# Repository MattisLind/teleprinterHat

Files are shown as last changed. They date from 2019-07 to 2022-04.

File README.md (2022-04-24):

# teleprinterHat
A RaspberryPi HAT that interfaces a old school teleprinter

Finished board

Schematic

## History
Some time ago I started planning to get an old Lorenz Lo15 teleprinter working. Then arose the question about how to interface those old machines to the real world. While investigating this I gained quite some knowledge of teleprinter interfacing and Telex networks. For example the normal line voltage of a US teleprinter line is 120VDC and the current is 60 mA.

Preferbly the interfacing should be as simple and small as possible. Using some big expensive 50 Hz 120 VAC transformer, rectifier and 2kOhm 6W resistor was not on the table.

Preferbly the circuit should be able to run off a standard USB charger. I.e. 5V 500mA. Experimenting a bit with a stepup circuit gave that is perfectly possibly to step up 5V to 120V. SO one could ask how could a 5V 500 mA supply be able to supply the power for a 120V 60mA load. Of course it cannot, but the problem lies in the fact tat most of the power is absorbed in the current limiting 2kOhm resistor of the old school circuit. The actual teleprinter has an internal resistance of approximately 100 Ohm. So why 120V? The reason for 120V is to achieve a fast pull of the magnet inside the teleprinter. After the initial pull the steady state voltage drop is between 5 to 10 V at 60mA. 

When I started to work with this project I also made an announcment in the i-Telex forum and got a reply from Jochen that had done something similar and the same point in time. What a coincidence! [piTelex project](https://github.com/fablab-wue/piTelex)

Jochen have compiled a lot of interesting and useful information there but the project is based on a Raspberry Pi and cannt be used stand alone. One of my requirements are that it should be able to run completely stand alone. I don't want the bloat of a Linux kernel just to push a few bytes back and forth!

## Requirments

So I put together a list of requirments

1. Shall only need 5V supply. The generation of up 120V DC is built into the device. Using a step-up converter.
2. Low power consumption. No 6W 2kOhm resistor. Use PWM to control the current through the solenoid. 
3. Configurable for 60mA, 40mA and 20mA current loop.
4. ~~Automatically detect the line voltage to use based on line current and required rise time of current through coil. Measure what kinde of loop inductance there is and adapt to a possibly resistive remote.~~ Deemed not possible with current design.
5. Interface directly to RS-232-E levels on board. (option) using a MAX232 or equivalent and a couple of capacitors
6. Interface directly to USB using FTDI chip on board (option)
7. Do baudot to ASCII conversion locally.
8. Do baudrate adaption locally. Configurable teleprinter baudrate to support at least 45,5, 50, 56, 75, 100 and 110 bps.
9. Configurable uplink RS-232 interface 50, 75, 110, 150, 300 bps to adapt to all sorts of hosts.
10. Dimensions that fits the Rpi Zero preferbly but if it is getting to crammed a standar Rpi HAT is the choice.
11. The RPI should be able to control all settings of the device from GPIO ports. Possibly use SPI to make more advanced configuration possible.
13. LEDs connected to RPi GPIOs to indicate mode or state in RPi Software.
14. Jumpers connected to the RPI GPIOs to control the RPI software and selection om mode of operation.
15. The RPi shall automatically boot up and select operating mode depending on jumpers. For example i-Telex or news RSS, RasPi serial console. No interaction using screen or keyboard connected to the RPi shall be necessary.
16. Relay to support reversal of polarity of the line current (optional)
17. Be able to drive a SSR that can be used to enable power to the teleprinter
18. Diagnostic LED to indicate line malfunction. I.e. to detect an open loop 
19. Current loop interface to support old PDP-11 current loops using opto couplers.
20. Use two 2.5 mm mono plugs for interfacing the teleprinter.
21. Diagnostic LED to indicate what line voltage is selected. Maybe multicolor RGB LED?
22. RX and TX LEDs
23. Support for FSG device (optional)
24. A few test sequences are built in. Continous RY and "The quick brown fox jumps over the lazy dog"
25. Flow control using XON/XOFF, RTS/CTS or DSR/DTR. Selcteable using jumpers. Both via USB/FTDI or RS-232

## Stepup converter

The first thing to verify is that the idea of the step up converter was ok. I did a small circuit board to check the circuit and during this I found that the parameters of the coil si very importantant. It has to have a high enough Isat. Then the choice of MOSFET is important. The MOSFET has to full turn on at only 5V gate voltage which is what is available in this circuit. Thus Vgs(ON) is of high interest. Then to deliver as much of the 5V into the coil means that as little loss of energy in the MOSFET is important. The rDS(ON) is the parameter to look for. 

Step up hook up

It turned out that this circuit worked well and could easily deliver 120VDC.

## Using PWM to control the selector magnet.

The main idea with this circuit is to generate the required 60mA with as litle loss as possible. By measuring the current in the loop using a small resistance and then hysteresis regulate the current using a PNP transistor as switch. The current is feed through a small inductor which will not saturate. 

As the switch transistor is swithced on the current in the inductor will increase with time. When it reach the upper hysteresis limit the transistor will switch off. The current in the inductance will continue to flow through the diode and the resistor. As the current reaches the lower limit the transistor will switch on again. 

The receiver magnet inductance will only come into play when going from sending a space bit to a mark bit. Then the large total inductance will keep the regulator switched on for several milliseconds depending on the inductance in the magenet. As soon as the line current level is reached the magnetcoil is fully saturated and will act as a pure resistance. The implementation is based on a op-amp for measuring the differential volatage of the current measuring resistor. Then a fast comparator with a 5% hysterisis band generates a square wave from the incoming sawtooth signal. This squarewave then drives the switch transistors. 

The transistor switch is composed of a PNP transistor as the main switch transistor and a NPN level cvonversion transistor driving the PNP transistor through a resistance.

The reference voltage to the hysteresis comparator is supplied from a PWM signal output of the mikroprocessor. Thereby making it possible to control the current level through software. The PWM signal is low pass filtered in a simple RC network and then buffered through a buffering op-amp.

I did a quick mockup with components at hand but it turned out that the comparator needed to be pretty fast and the transistor switch as well. It simply didn't work very well. I decided to try to do simulations in LTspice before doing further breadboarding. 

Searches on internet gave a decent circuit for a P-MOS FET based switch. Simulations in LTspice gave proper values for resistors and capacitors and it was time to make a peroper board.

Current source prototype

Schematic.

Current source prototype schematic

The design also included an PNP and NPN transistor to handle keying of the sening signal.

A simple NPN transistor is used to key the current in the loop ON/OFF. This has to be done without any free-wheeling diode since otherwise the release of the magnet when swithcing of the current will be very much delayed and might not even happen at all. 

Initial tests showed good performance. It could regulate the desired current at varying line voltages without any problem.

Current source regulating

This picture show the voltage over the measurement resistor. The scale is 100mV per division and the resistor is 51 ohm so the interval it is regulating over is +/- 2mA as designed.

Running the circuit with the actual Lorenz Lo15 teleprinter also yielded good results.

Current source regulating

Keying the signal, 90V line voltage, 40 mA line current. The large spikes are created by the selector magnet as the switch cuts off. Had initial problems that the choosen PNP transistor was unable to cope with these. Intalled a 300 V PNP transistor and a MOV to handle the spikes. Worked well. But I am considering using a TVS instead.

Current source regulating

This picture shows when regulating the 40mA output to the selector magnet when the line is in marking state.

## Prototyping the Step up converter and current source 

I already did a prototype of the step-up converter. But the MOSFET used was quite big and overdimensioned. I also wanted to use a proper gate driver as well as off load the micro controller doing the chore of keeping the PWM rate continuosly measuring the output voltage. A separate, very small, switch control IC, cheap as well, was a better choice. So I designed another prototype board to test out these concept as well as testing the current loop circuit.

Current source regulating

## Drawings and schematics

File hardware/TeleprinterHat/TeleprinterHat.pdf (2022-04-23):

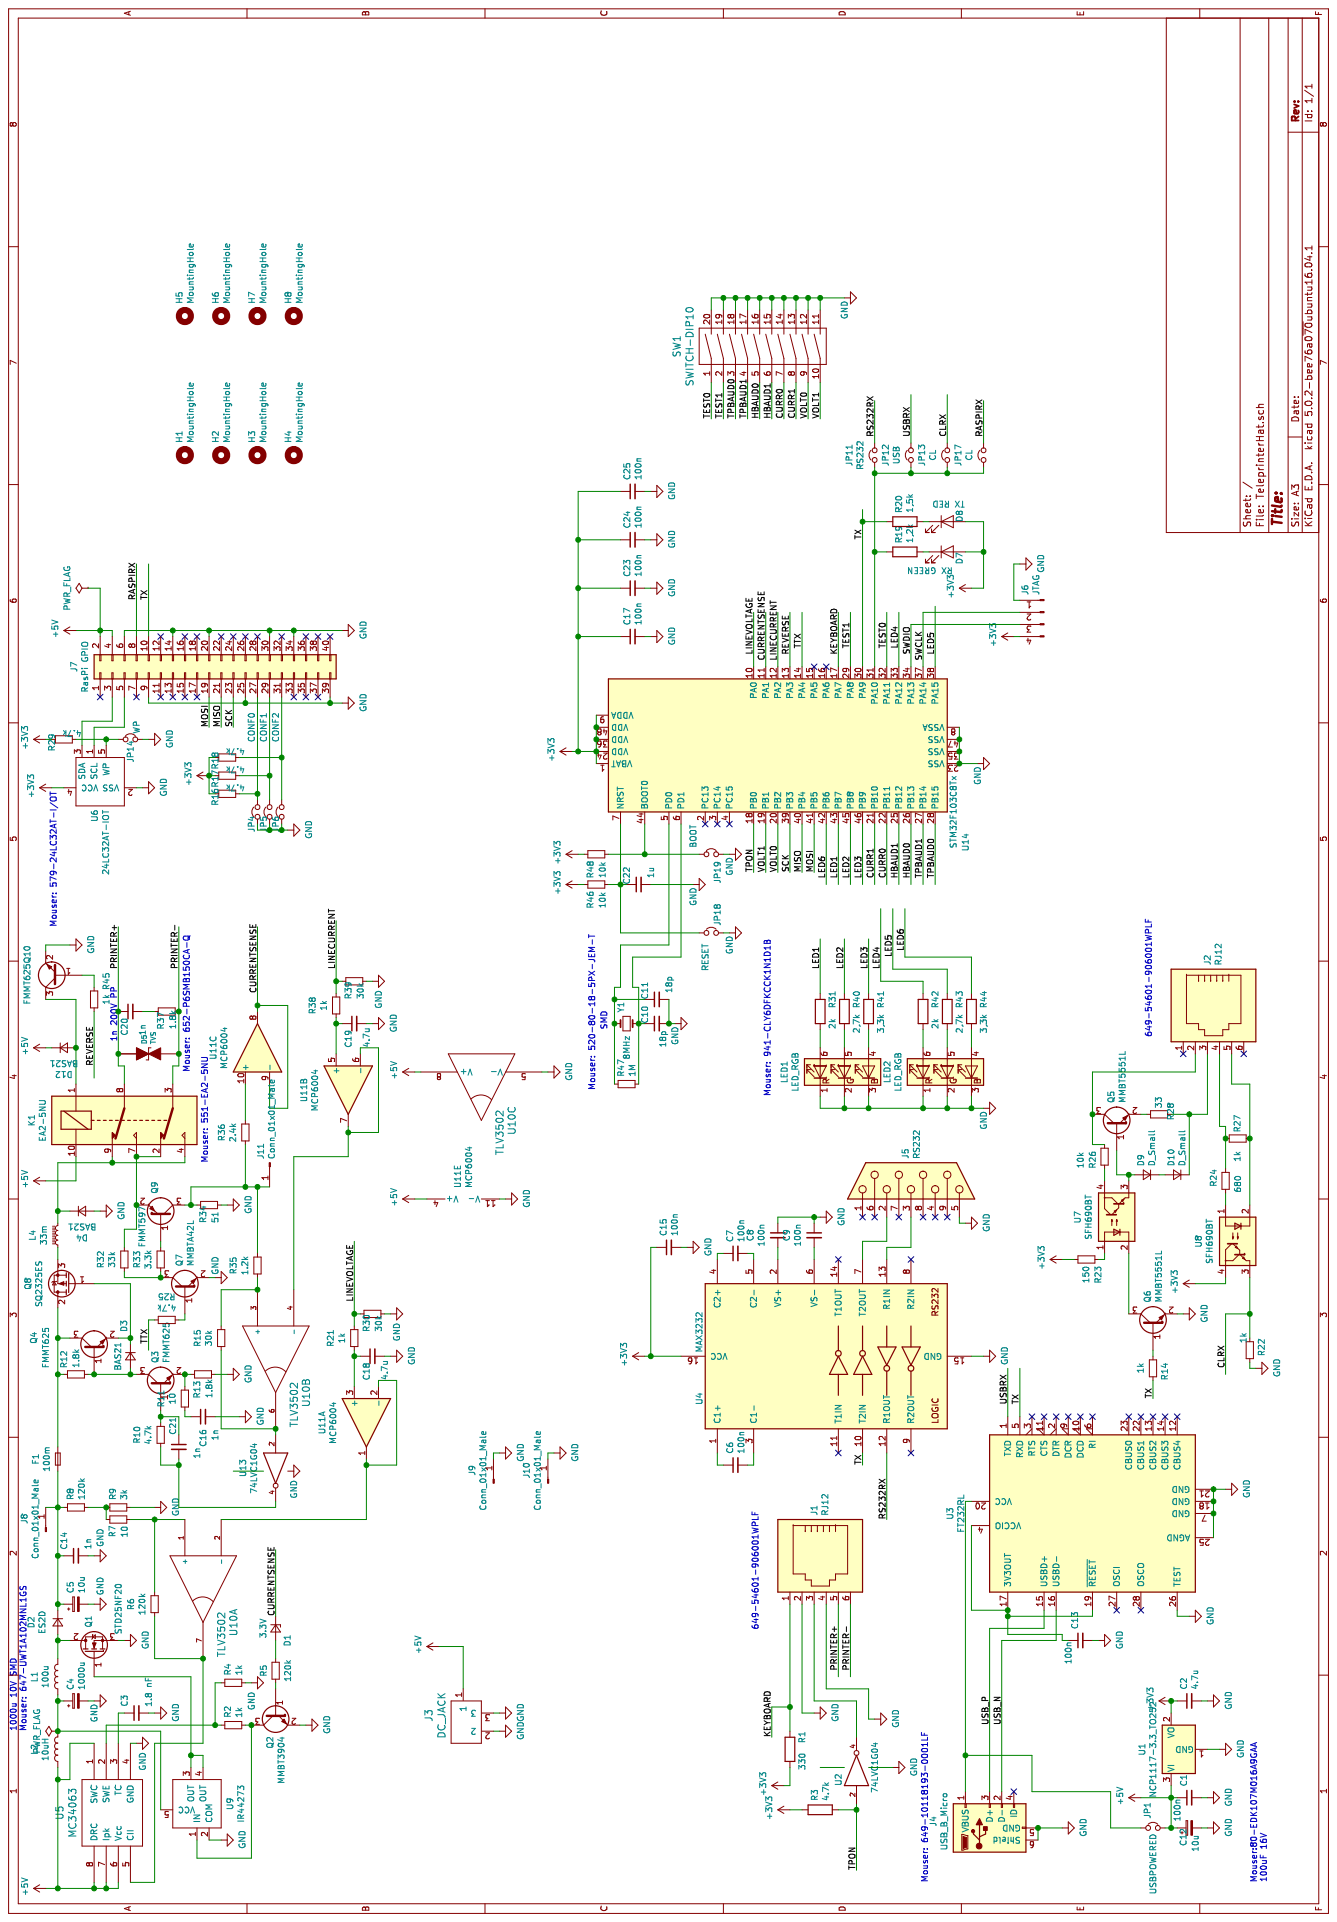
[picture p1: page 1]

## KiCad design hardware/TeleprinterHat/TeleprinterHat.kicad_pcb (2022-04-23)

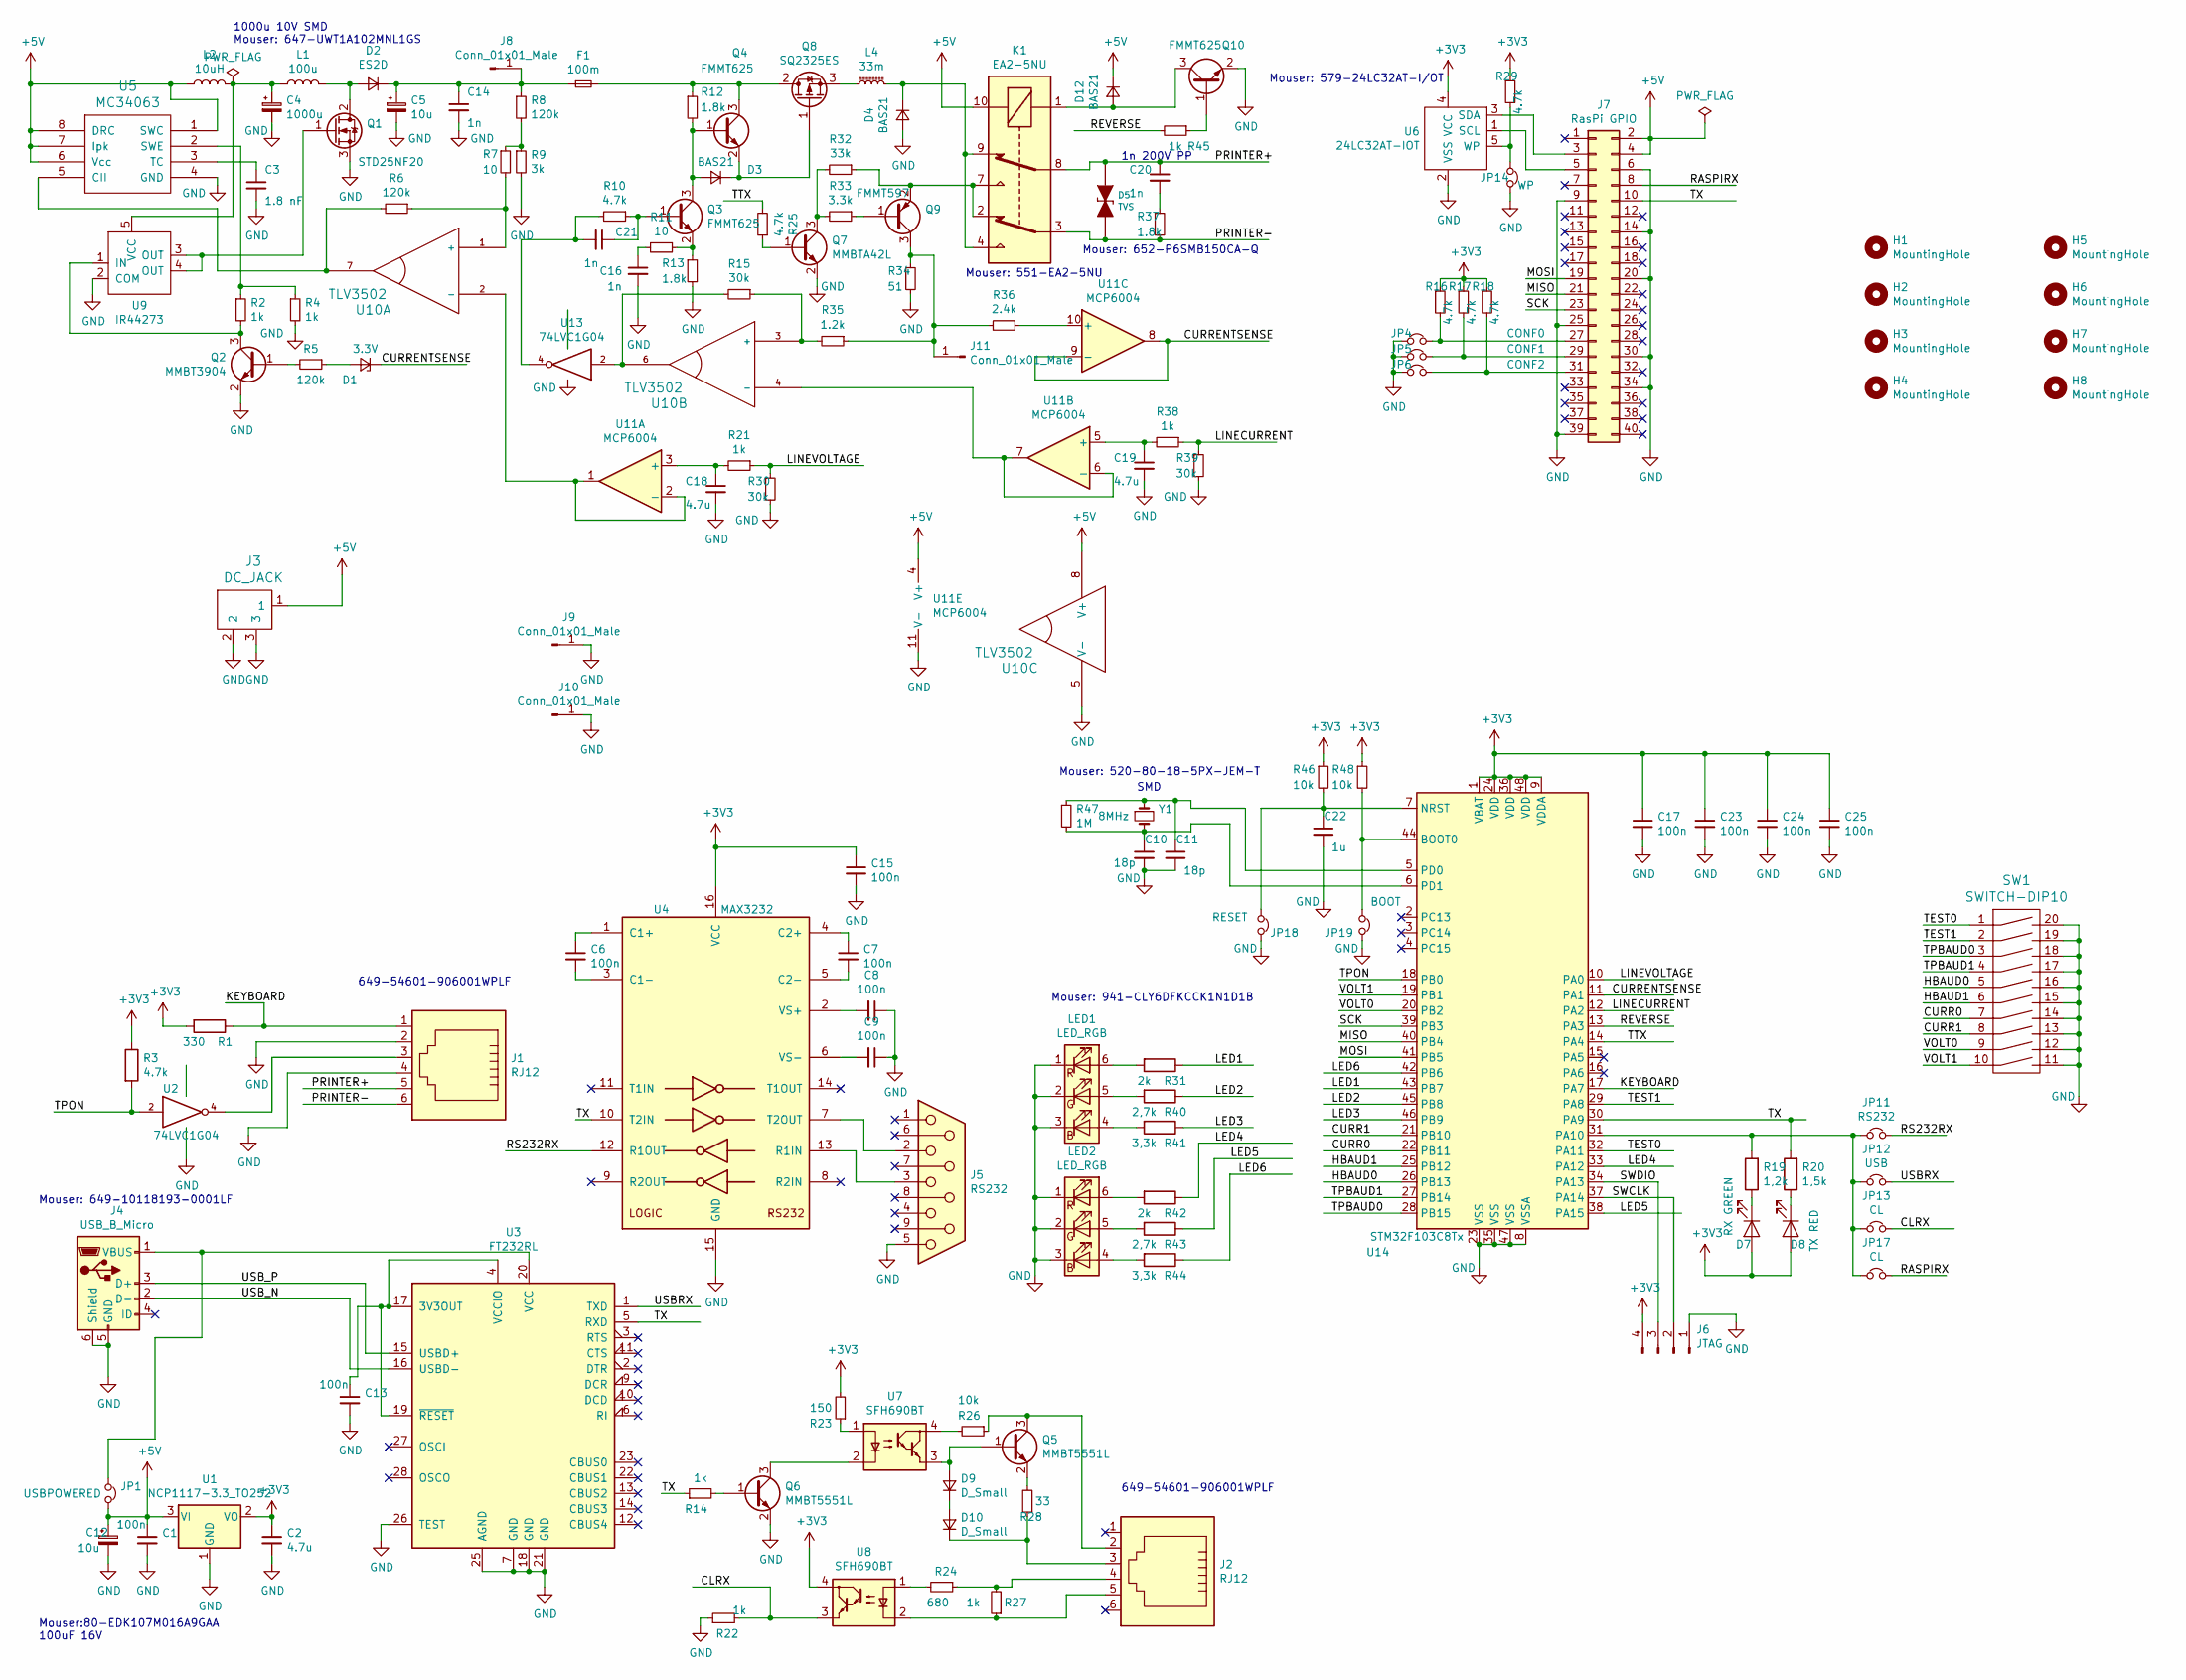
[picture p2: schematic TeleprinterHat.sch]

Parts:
C1, C6, C7, C8, C9, C13, C15, C17, C23, C24, C25: 100n; C_0805_2012Metric
C2, C18, C19: 4.7u; C_0805_2012Metric
C3: 1.8 nF; C_0805_2012Metric
C4: 1000u; CP_Elec_10x7.7
C5: 10u; CP_Radial_D8.0mm_P3.50mm
C10, C11: 18p; C_0805_2012Metric
C12: 10u; C_0805_2012Metric
C14, C16, C21: 1n; C_0805_2012Metric
C20: 1n; C_Rect_L7.0mm_W2.0mm_P5.00mm
C22: 1u; C_0805_2012Metric
D1: 3.3V; D_SOD-123
D2: ES2D; D_SMB_Handsoldering
D3, D4, D12: BAS21; SOT-23
D5: TVS; D_SMB_Handsoldering
D7: RX GREEN; LED_0805_2012Metric_Castellated
D8: TX RED; LED_0805_2012Metric_Castellated
D9, D10: D_Small; D_SOD-123
F1: 100m; Fuse_0603_1608Metric_Pad1.05x0.95mm_HandSolder
H1, H2, H3, H4, H5, H6, H7, H8: MountingHole; MountingHole_2.7mm_M2.5
J1, J2: RJ12; RJ12_Amphenol_54601
J3: DC_JACK; BarrelJack_Wuerth_6941xx301002
J4: USB_B_Micro; USB_Micro-B_Amphenol_10103594-0001LF_Horizontal
J5: RS232; DSUB-9_Female_Horizontal_P2.77x2.84mm_EdgePinOffset9.90mm_H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
J6: JTAG; PinHeader_1x04_P2.54mm_Vertical
J7: RasPi GPIO; PinSocket_2x20_P2.54mm_Vertical
J8, J9, J10, J11: Conn_01x01_Male; PinHeader_1x01_P2.54mm_Vertical
JP1: USBPOWERED; PinHeader_1x02_P2.54mm_Vertical
JP4: CONF0; PinHeader_1x02_P2.54mm_Vertical
JP5: CONF1; PinHeader_1x02_P2.54mm_Vertical
JP6: CONF2; PinHeader_1x02_P2.54mm_Vertical
JP11: RS232; PinHeader_1x02_P2.54mm_Vertical
JP12: USB; PinHeader_1x02_P2.54mm_Vertical
JP13, JP17: CL; PinHeader_1x02_P2.54mm_Vertical
JP14: WP; PinHeader_1x02_P2.54mm_Vertical
JP18: RESET; PinHeader_1x02_P2.54mm_Vertical
JP19: BOOT; PinHeader_1x02_P2.54mm_Vertical
K1: EA2-5NU; DIP-10_W7.62mm
L1: 100u; Wurth TIF Radial 1018
L2: 10uH; L_Radial_D7.0mm_P3.00mm
L4: 33m; L_Radial_D12.0mm_P6.00mm_MuRATA_1900R
LED1, LED2: LED_RGB; LED_Avago_PLCC6_3x2.8mm
Q1: STD25NF20; TO-252-3_TabPin2
Q2: MMBT3904; SOT-23
Q3, Q4, Q10: FMMT625; SOT-23
Q5, Q6: MMBT5551L; SOT-23
Q7: MMBTA42L; SOT-23
Q8: SQ2325ES; SOT-23
Q9: FMMT597; SOT-23
R1: 330; R_0805_2012Metric
R2, R4, R14, R21, R22, R27, R38, R45: 1k; R_0805_2012Metric
R3, R10, R16, R17, R18, R25, R29: 4.7k; R_0805_2012Metric
R5, R6, R8: 120k; R_0805_2012Metric
R7, R11: 10; R_0805_2012Metric
R9: 3k; R_0805_2012Metric
R12, R13, R37: 1.8k; R_0805_2012Metric
R15, R30, R39: 30k; R_0805_2012Metric
R19: 1,2k; R_0805_2012Metric
R20: 1,5k; R_0805_2012Metric
R23: 150; R_0805_2012Metric
R24: 680; R_0805_2012Metric
R26, R46, R48: 10k; R_0805_2012Metric
R28: 33; R_0805_2012Metric
R31, R42: 2k; R_0805_2012Metric
R32: 33k; R_0805_2012Metric
R33: 3.3k; R_0805_2012Metric
R34: 51; R_0805_2012Metric
R35: 1.2k; R_0805_2012Metric
R36: 2.4k; R_0805_2012Metric
R40, R43: 2,7k; R_0805_2012Metric
R41, R44: 3,3k; R_0805_2012Metric
R47: 1M; R_0805_2012Metric
SW1: SWITCH-DIP10; DIP-20_W7.62mm
U1: NCP1117-3.3_TO252; TO-252-2
U2, U13: 74LVC1G04; SOT-23-5_HandSoldering
U3: FT232RL; SSOP-28_5.3x10.2mm_P0.65mm
U4: MAX3232; SOIC-16_3.9x9.9mm_P1.27mm
U5: MC34063; SOIC-8_3.9x4.9mm_P1.27mm
U6: 24LC32AT-IOT; SOT-23-5_HandSoldering
U7, U8: SFH690BT; SO-4_4.4x3.6mm_P2.54mm
U9: IR44273; SOT-23-5_HandSoldering
U10: TLV3502; SOT-23-8_Handsoldering
U11: MCP6004; SOIC-14_3.9x8.7mm_P1.27mm
U14: STM32F103C8Tx; LQFP-48_7x7mm_P0.5mm
Y1: 8MHz; Crystal_SMD_HC49-SD

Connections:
+5V: C1.1, C12.1, D12.1 (K), J3.1, J7.2, J7.4, JP1.2, K1.10, L2.1, U1.3 (VI), U5.1 (SWC), U5.6 (Vcc), U5.7 (Ipk), U5.8 (DRC), U10.8 (V+), U11.4 (V+)
/CLRX: JP13.2, R22.2, U8.3
/CURR0: SW1.7, U14.22 (PB11)
/CURR1: SW1.8, U14.21 (PB10)
/CURRENTSENSE: D1.1 (K), U11.8, U11.9 (-), U14.11 (PA1)
/HBAUD0: SW1.5, U14.26 (PB13)
/HBAUD1: SW1.6, U14.25 (PB12)
/KEYBOARD: J1.1, R1.1, U14.17 (PA7)
/LED1: R31.1, U14.43 (PB7)
/LED2: R40.1, U14.45 (PB8)
/LED3: R41.1, U14.46 (PB9)
/LED4: R42.1, U14.33 (PA12)
/LED5: R43.1, U14.38 (PA15)
/LED6: R44.1, U14.42 (PB6)
/LINECURRENT: R38.1, R39.1, U14.12 (PA2)
/LINEVOLTAGE: R21.1, R30.1, U14.10 (PA0)
/MISO: J7.21, U14.40 (PB4)
/MOSI: J7.19, U14.41 (PB5)
/PRINTER+: C20.1, D5.1 (A), J1.5, K1.8
/PRINTER-: D5.2 (K), J1.6, K1.3, R37.2
/RASPIRX: J7.8, JP17.2
/REVERSE: R45.2, U14.13 (PA3)
/RS232RX: JP11.2, U4.12 (R1OUT)
/SCK: J7.23, U14.39 (PB3)
/TEST0: SW1.1, U14.32 (PA11)
/TEST1: SW1.2, U14.29 (PA8)
/TPBAUD0: SW1.3, U14.28 (PB15)
/TPBAUD1: SW1.4, U14.27 (PB14)
/TPON: R3.2, U2.2, U14.18 (PB0)
/TTX: R25.2, U14.14 (PA4)
/TX: J7.10, R14.1, R20.2, U3.5 (RXD), U4.10 (T2IN), U14.30 (PA9)
/USBRX: JP12.2, U3.1 (TXD)
/USB_N: J4.2 (D-), U3.16 (USBD-)
/USB_P: J4.3 (D+), U3.15 (USBD+)
/VOLT0: SW1.9, U14.20 (PB2)
/VOLT1: SW1.10, U14.19 (PB1)
unnamed: C3.1, U5.3 (TC)
unnamed: C4.1, L1.1, L2.2, U9.5 (VCC)
unnamed: C6.1, U4.1 (C1+)
unnamed: C6.2, U4.3 (C1-)
unnamed: C7.1, U4.4 (C2+)
unnamed: C7.2, U4.5 (C2-)
unnamed: C8.2, U4.2 (VS+)
unnamed: C9.2, U4.6 (VS-)
unnamed: C10.1, R47.2, U14.6 (PD1), Y1.2
unnamed: C11.1, R47.1, U14.5 (PD0), Y1.1
unnamed: C13.1, U3.4 (VCCIO), U3.17 (3V3OUT), U3.19 (~RESET~)
unnamed: C5.1, C14.1, D2.1 (K), F1.1, J8.1, R8.1
unnamed: C16.1, R11.2
unnamed: C18.1, R21.2, U11.3 (+)
unnamed: C19.1, R38.2, U11.5 (+)
unnamed: C20.2, R37.1
unnamed: C21.1, Q3.1 (B), R10.1
unnamed: C21.2, R10.2, U13.4
unnamed: C22.1, JP18.1, R46.2, U14.7 (NRST)
unnamed: D1.2 (A), R5.1
unnamed: D2.2 (A), L1.2, Q1.2 (D)
unnamed: D3.1 (K), Q4.2 (E), Q8.1 (G)
unnamed: D3.2 (A), Q3.3 (C), Q4.1 (B), R12.2
unnamed: D4.1 (K), K1.4, K1.9, L4.2
unnamed: D9.2 (A), Q5.1 (B), U7.3
unnamed: D10.1 (K), J2.3, R28.1
unnamed: D9.1 (K), D10.2 (A)
unnamed: D12.2 (A), K1.1, Q10.3 (C)
unnamed: F1.2, Q4.3 (C), Q8.2 (D), R12.1
unnamed: J1.3, U2.4
unnamed: J2.2, Q5.3 (C), R26.1
unnamed: J2.4, R24.1, R27.2
unnamed: J2.5, R27.1, U8.2
unnamed: J4.1 (VBUS), JP1.1, U3.20 (VCC)
unnamed: J5.2, U4.7 (T2OUT)
unnamed: J5.3, U4.13 (R1IN)
unnamed: J7.3, U6.3 (SDA)
unnamed: J7.5, U6.1 (SCL)
unnamed: J7.27, JP4.2, R16.2
unnamed: J7.29, JP5.2, R17.2
unnamed: J7.31, JP6.2, R18.2
unnamed: J11.1, Q9.3 (C), R34.1, R35.1, R36.2
unnamed: JP11.1, JP12.1, JP13.1, JP17.1, R19.2, U14.31 (PA10)
unnamed: JP14.1, R29.2, U6.5 (WP)
unnamed: JP19.1, R48.2, U14.44 (BOOT0)
unnamed: K1.2, K1.7, Q9.2 (E), R32.1
unnamed: L4.1, Q8.3 (S)
unnamed: LED1.4 (BA), R41.2
unnamed: LED1.5 (GA), R40.2
unnamed: LED1.6 (RA), R31.2
unnamed: LED2.4 (BA), R44.2
unnamed: LED2.5 (GA), R43.2
unnamed: LED2.6 (RA), R42.2
unnamed: Q1.1 (G), U9.3 (OUT), U9.4 (OUT)
unnamed: Q2.1 (B), R5.2
unnamed: Q2.3 (C), R2.2, U9.1 (IN)
unnamed: Q3.2 (E), R11.1, R13.1
unnamed: Q5.2 (E), R28.2
unnamed: Q6.1 (B), R14.2
unnamed: Q6.3 (C), U7.2
unnamed: Q7.1 (B), R25.1
unnamed: Q7.3 (C), R32.2, R33.2
unnamed: Q9.1 (B), R33.1
unnamed: Q10.1 (B), R45.1
unnamed: R2.1, R4.1, U5.2 (SWE)
unnamed: R6.1, R7.2, U10.1 (+)
unnamed: R6.2, U5.5 (CII), U10.7
unnamed: R7.1, R8.2, R9.1
unnamed: R15.1, R35.2, U10.3 (+)
unnamed: R15.2, U10.6, U13.2
unnamed: R23.1, U7.1
unnamed: R24.2, U8.1
unnamed: R26.2, U7.4
unnamed: R36.1, U11.10 (+)
unnamed: U10.2 (-), U11.1, U11.2 (-)
unnamed: U10.4 (-), U11.6 (-), U11.7

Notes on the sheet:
Mouser: 551-EA2-5NU
Mouser: 941-CLY6DFKCCK1N1D1B
SMD
1n 200V PP
Mouser: 649-10118193-0001LF
1000u 10V SMD Mouser: 647-UWT1A102MNL1GS
Mouser: 520-80-18-5PX-JEM-T
Mouser: 579-24LC32AT-I/OT
Mouser:80-EDK107M016A9GAA 100uF 16V
Mouser: 652-P6SMB150CA-Q
649-54601-906001WPLF

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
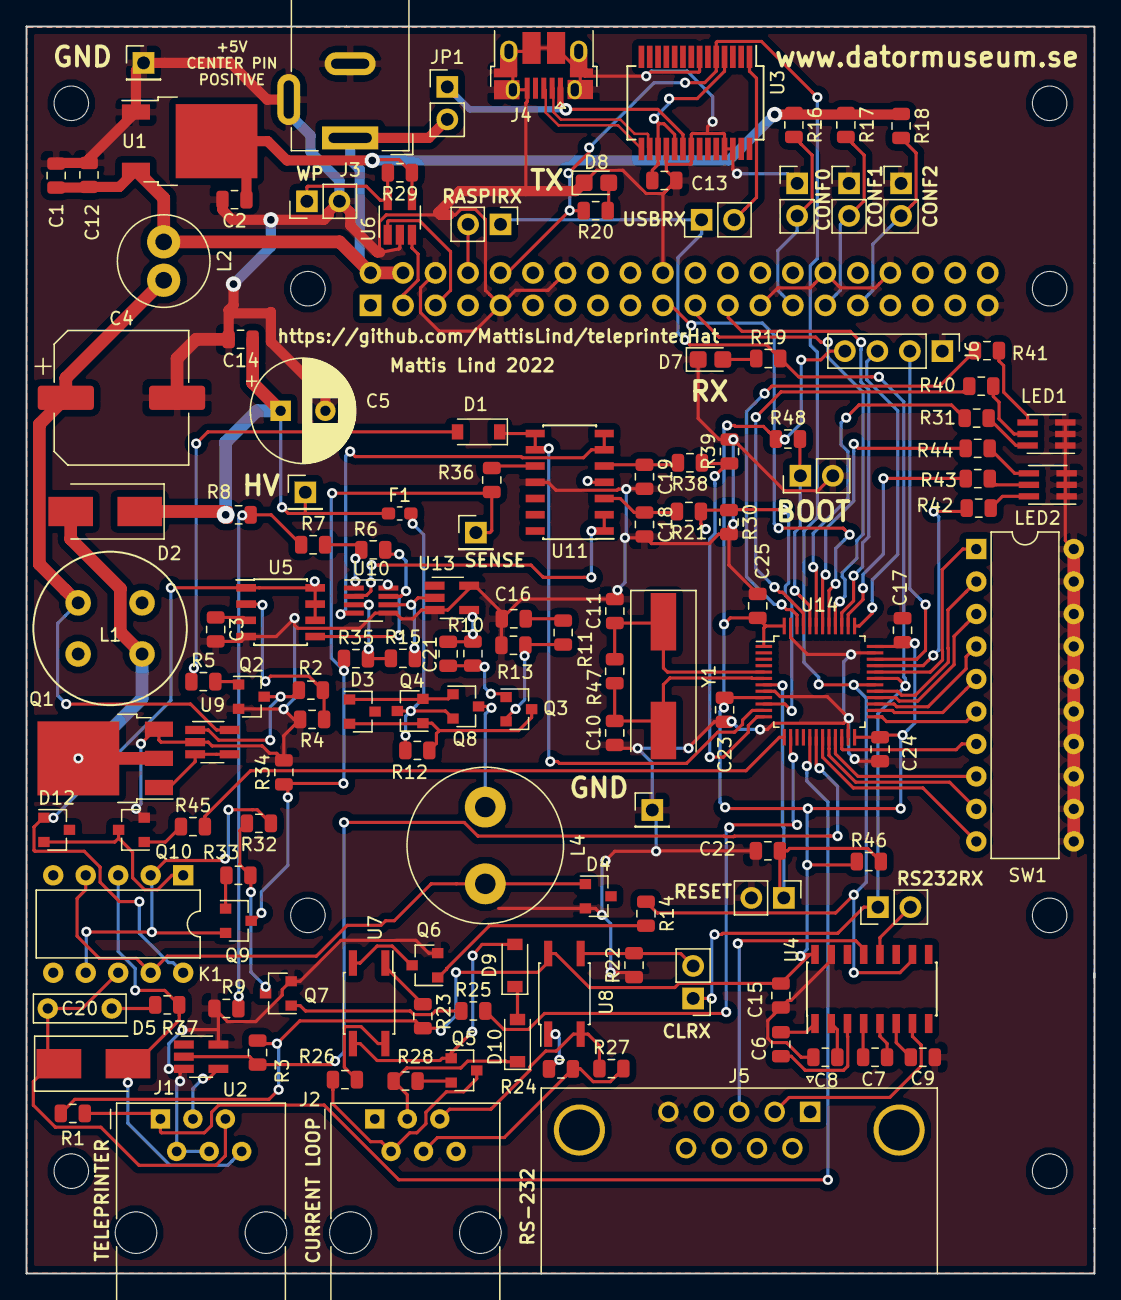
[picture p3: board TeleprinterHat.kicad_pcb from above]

Board: 2 copper layers, 83.5 x 97.5 mm, 145 parts (1 on the bottom side), 118 nets.

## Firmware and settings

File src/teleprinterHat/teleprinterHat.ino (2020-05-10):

// Use environment: 
// Board: STM32F1 boards (STM32DUINO.COM) Generic STM32F103C series
// Variant: STM32F103CB (20k RAM 128k FLASH)
// Upload Method: STLink
// CPU Speed: 72 MHz (Normal)
// Optimize: Smallest (default)

// Code size when compiled 40248 bytes. Global variables use 12688 bytes.

#define LED_RATE 1250    // in microseconds; should give 0.5Hz toggles
#include "RingBuffer.h"
#include "SoftUART.h"
#include "BaudotCodec.h"

class RingBuffer txBuffer;
class RingBuffer rxBuffer;
class BaudotCodec baudotCodec(1);



const int pwmOutPin = PA0; // pin10
HardwareTimer pwmtimer(2);

// We'll use timer 2
HardwareTimer timer(1);

uint16 maxduty;  
uint32 period, mypulse;
int duty=2200;

int shiftMode = 0;
int state = -1;
char ch;

void txBit (char bit) {
  if (bit & 1) {
    digitalWrite(PA2,HIGH);  
  } else {
    digitalWrite(PA2,LOW);
  }
}

char rxOut = 1;
int rxSum=16;

char rxBit () {
  char in = (~digitalRead(PA6)) & 1;
  if (in==1) {
     rxSum++;
     if (rxSum>16) rxSum=16;
  } else {
    rxSum--;
    if (rxSum<0) rxSum=0;
  }
  if (rxOut == 1 && rxSum < 8) {
     rxOut = 0;
  }
  if (rxOut == 0 && rxSum > 8) {
     rxOut = 1;
  }
  digitalWrite(PC14, rxOut);
  return rxOut;
}

int debugState = 0;

void debug () {
  debugState ^= 1;
  digitalWrite (PC15, debugState);  
}

class SoftUART softUART(rxBit, txBit, &txBuffer, &rxBuffer, debug);

void setup() {
  
  rxBuffer.initBuffer();
  txBuffer.initBuffer();
  pinMode(PC13, OUTPUT);
  pinMode(PC14, OUTPUT);
  pinMode(PC15, OUTPUT);
  digitalWrite (PC15, 0);
  pwmtimer.pause();
  period = 40; // PWM period in useconds, freq 4Hz
  maxduty = pwmtimer.setPeriod(period);
  pwmtimer.refresh();
  pwmtimer.resume();
  pinMode(pwmOutPin, PWM);
  pinMode(PA1, PWM);
  pwmWrite(PA1, 1800); // 1000 = 21mA 1900 = 43 mA 
  pinMode(PA2, OUTPUT);
  pinMode(PA6, INPUT);
  pinMode(PA4, INPUT_ANALOG);
  pinMode(PA5, INPUT_ANALOG);
  Serial1.begin(1200);
  digitalWrite(PA2,HIGH);
  

      // Pause the timer while we're configuring it
    timer.pause();

    // Set up period
    timer.setPeriod(LED_RATE); // in microseconds

    // Set up an interrupt on channel 1
    timer.setChannel1Mode(TIMER_OUTPUT_COMPARE);
    timer.setCompare(TIMER_CH1, 1);  // Interrupt 1 count after each update
    timer.attachCompare1Interrupt(handler_led);

    // Refresh the timer's count, prescale, and overflow
    timer.refresh();

    // Start the timer counting
    timer.resume();  
}

volatile int threshold = 0;


volatile int sampleCounter=0;

void handler_led(void) {
   sampleCounter++;
   if (sampleCounter == 8) {
    sampleCounter=0;
    softUART.baudotTransmitStateMachine(); 
   }
   softUART.baudotReceiveStateMachine();
}


void loop() {
  int out, rxChar;
  duty += 1 * (2700-analogRead(PA5));
  if (duty > 2400) {
    duty=2400;
  }
  if (duty < 0) {
    duty=0;
  }

  pwmWrite(pwmOutPin, duty); // 0<=duty<=maxduty
  
  if (!txBuffer.isBufferFull()) {
    if (shiftMode) {
       out = baudotCodec.asciiToBaudot(ch, &shiftMode);
       txBuffer.writeBuffer(out);
    } else {
      if (Serial1.available()) {
        ch = Serial1.read();
        out = baudotCodec.asciiToBaudot(ch, &shiftMode);
        txBuffer.writeBuffer(out);  
      }
    }
  }
  if (!rxBuffer.isBufferEmpty()) {
    rxChar = rxBuffer.readBuffer();
    out = baudotCodec.baudotToAscii(rxChar);
    if (out != -1) {
      Serial1.write(out);
    }
  }
  
}

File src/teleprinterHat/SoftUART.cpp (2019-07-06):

#include "SoftUART.h"
#include "RingBuffer.h"
#include <stdio.h>


SoftUART::SoftUART(readFuncType readFunc, writeFuncType writeFunc, class RingBuffer * txB, class RingBuffer * rxB, debugFuncType dbf) {
  debug = dbf;
  rxBit=readFunc;
  txBit=writeFunc;
  txBuffer = txB;
  rxBuffer = rxB;
  rxState=0;
  sampleCounter = 0;
  bitCnt=0;
  baudotTxState = 0;
  lastChWasCr = 0;
}

void SoftUART::baudotReceiveStateMachine () {
  char bit;
  //printf("baudotReceiveStateMachine BEGIN, rxState=%d bitCnt=%d, sampleCounter=%d rxDataByte=%02X", rxState, bitCnt, sampleCounter,rxDataByte);
  switch (rxState) {
    case 0:   // Searching fo start bit 
      if (rxBit() == 0) {
	rxState = 1;
  sampleCounter=0;
      }
      break;
    case 1:  // Qualify start bit has to be 7 in a row.
      if (rxBit() == 0) {
	// Still a statbit. Need to count to 7 to find the middle of the start bit!
	if (sampleCounter >= 6) {
    debug();
	  rxState = 2;
	  sampleCounter = 0;
	  rxDataByte = 0;
	  bitCnt=0;
	} else {
	  sampleCounter ++;
	}
      } else {
	rxState = 0; // go back if a marking state detected again. False start bit !
      }
      break;
    case 2: // Sampling in the middle of the bit - first bit!
      bit = rxBit();
      if (sampleCounter >= 15) {
        debug();
	rxDataByte = rxDataByte >> 1;
	rxDataByte |= (1 & bit) << 4;
	bitCnt++;
	if (bitCnt==5) {
	  rxState=3;
	}
	sampleCounter=0;
      } else {
	sampleCounter++;
      }
      break;
    case 3: // 1.5 stop bits
      rxBit();
      if (sampleCounter < 22) {
	sampleCounter++;
      } else {
        debug();
	rxState = 0;
	rxBuffer->writeBuffer(rxDataByte);
      }
  }
}


void SoftUART::baudotTransmitStateMachine ()
{
  switch (baudotTxState) {
  case 0: // First half stop bit
    if (txBuffer->isBufferEmpty()) {
      return;
    }
    if (!lastChWasCr) { // make sure we send CR twice..
      txCh = txBuffer->readBuffer();
      if (txCh==8) lastChWasCr = 1;
    }
    else {
      lastChWasCr = 0;
    }
    txBit(0);
    baudotTxState++;
    break;
  case 1:
    txBit(0);
    baudotTxState++;
    break;
  case 2:
  case 3:
    txBit(txCh >> 0);
    baudotTxState++;
    break;
  case 4:
  case 5:
    txBit(txCh >> 1);
    baudotTxState++;
    break;
  case 6:
  case 7:
    txBit(txCh >> 2);
    baudotTxState++;
    break;
  case 8:
  case 9:
    txBit(txCh >> 3);
    baudotTxState++;
    break;
  case 10:
  case 11:
    txBit(txCh >> 4);
    baudotTxState++;
    break;
  case 12:
  case 13:
    txBit(1);
    baudotTxState++;
    break;
  case 14:
    txBit(1);
    baudotTxState=0;
    break;

  }
}

void SoftUART::poll() {

}

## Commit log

2019-06-21 Added more pictures on the prototypes
2019-06-21 Added the prototype step up converter schematic
2019-06-22 Added a small stupid unit test to see that the code for handling baudot conversionand buffering worked. Buffering did work but not the baudot conversion so some bugfixing was needed, which havt to go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
    [teleprinterHatTest.cc]
2019-06-22 Added code and test case for the tx state machine
2019-06-23 First try at a uart rx receiver.
2019-06-30 Moving around files to make the Arduino environment happy.
2019-06-30 Added flow control requirement. Rm req for auto coil detection
2019-06-30 First try to get the STM32 code working.
2019-06-30 The bit order was reversed.
    [SoftUART.cpp, teleprinterHat.ino]
2019-06-30 Fixed to use another output. Fixed sample rate.
    [teleprinterHat.ino]
2019-07-01 Updated test case to reflect the changed directory setup
2019-07-03 Filtering of the input signal to avoid short glitches.
    [teleprinterHat.ino]
2019-07-06 Debuging. Got the figures table a bit wrong some how. The sampleCOunter was not cleared which made sampling happen to early
    [SoftUART.cpp, teleprinterHat.ino]
2019-07-06 Fixed more mapping errors.
    [teleprinterHat.ino]
2020-05-10 Added a note on what environment to use when compiling in Arduino - Hard to remember and is not stored in some project file unfortunately.
2021-01-21 Added schematic for the full solution.
    [TeleprinterHat.kicad_pcb, TeleprinterHat.sch]
2021-04-25 Ready for routing board.
    [TeleprinterHat.kicad_pcb, TeleprinterHat.sch]
2022-01-17 Almost ready!
    [TeleprinterHat.kicad_pcb, TeleprinterHat.sch]
2022-04-23 Added pdf and SVG
    [TeleprinterHat.kicad_pcb, TeleprinterHat.sch]
2022-04-24 First spin of the board - has a few small issues.
